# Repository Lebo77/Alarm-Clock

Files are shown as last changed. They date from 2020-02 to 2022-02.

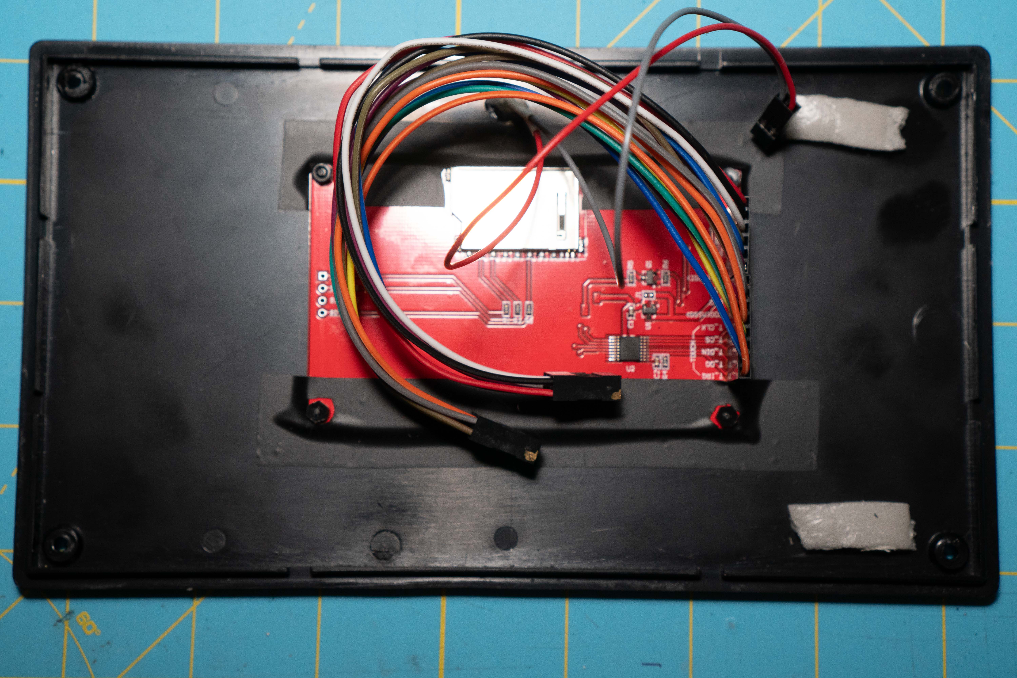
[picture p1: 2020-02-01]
Photos/DSC01666.jpg

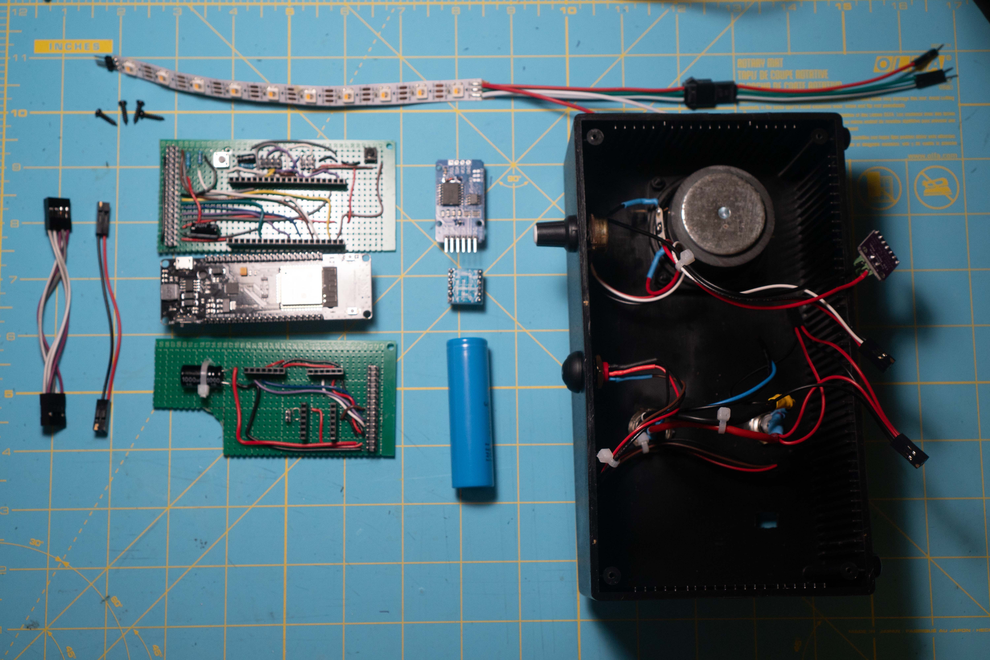
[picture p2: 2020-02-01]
Photos/DSC01659.jpg

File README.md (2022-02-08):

# Alarm-Clock
An ESP32 based alarm clock

This is a bedside alarm clock and light controller I developed. IT relies on a number of external libraries:

OpenWeather by Bodmer
  TFT_eSPI by Bodmer
  JSON_Decoder by Bodmer
  (Thanks Bodmer. This project would not be possible without you)
  ESP8266Audio by Earle F. Pillhower III
  NeoPixelBus by Makuna
  DS3232RTC by Jack Christensen
  Time by Paul Stoffregen
  The ESP32 Board support Package for Arduino by espressif

Thanks and credit to all of them. A few of these files are from Bodmer's libraries. They are included as that is how he intended for them to be employed in the project.

Also included in the KiCad Project directory are the PCB layout files and schematics I used to build my clock.

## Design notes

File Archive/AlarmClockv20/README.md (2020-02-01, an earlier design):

# Alarm-Clock
An ESP32 based alarm clock

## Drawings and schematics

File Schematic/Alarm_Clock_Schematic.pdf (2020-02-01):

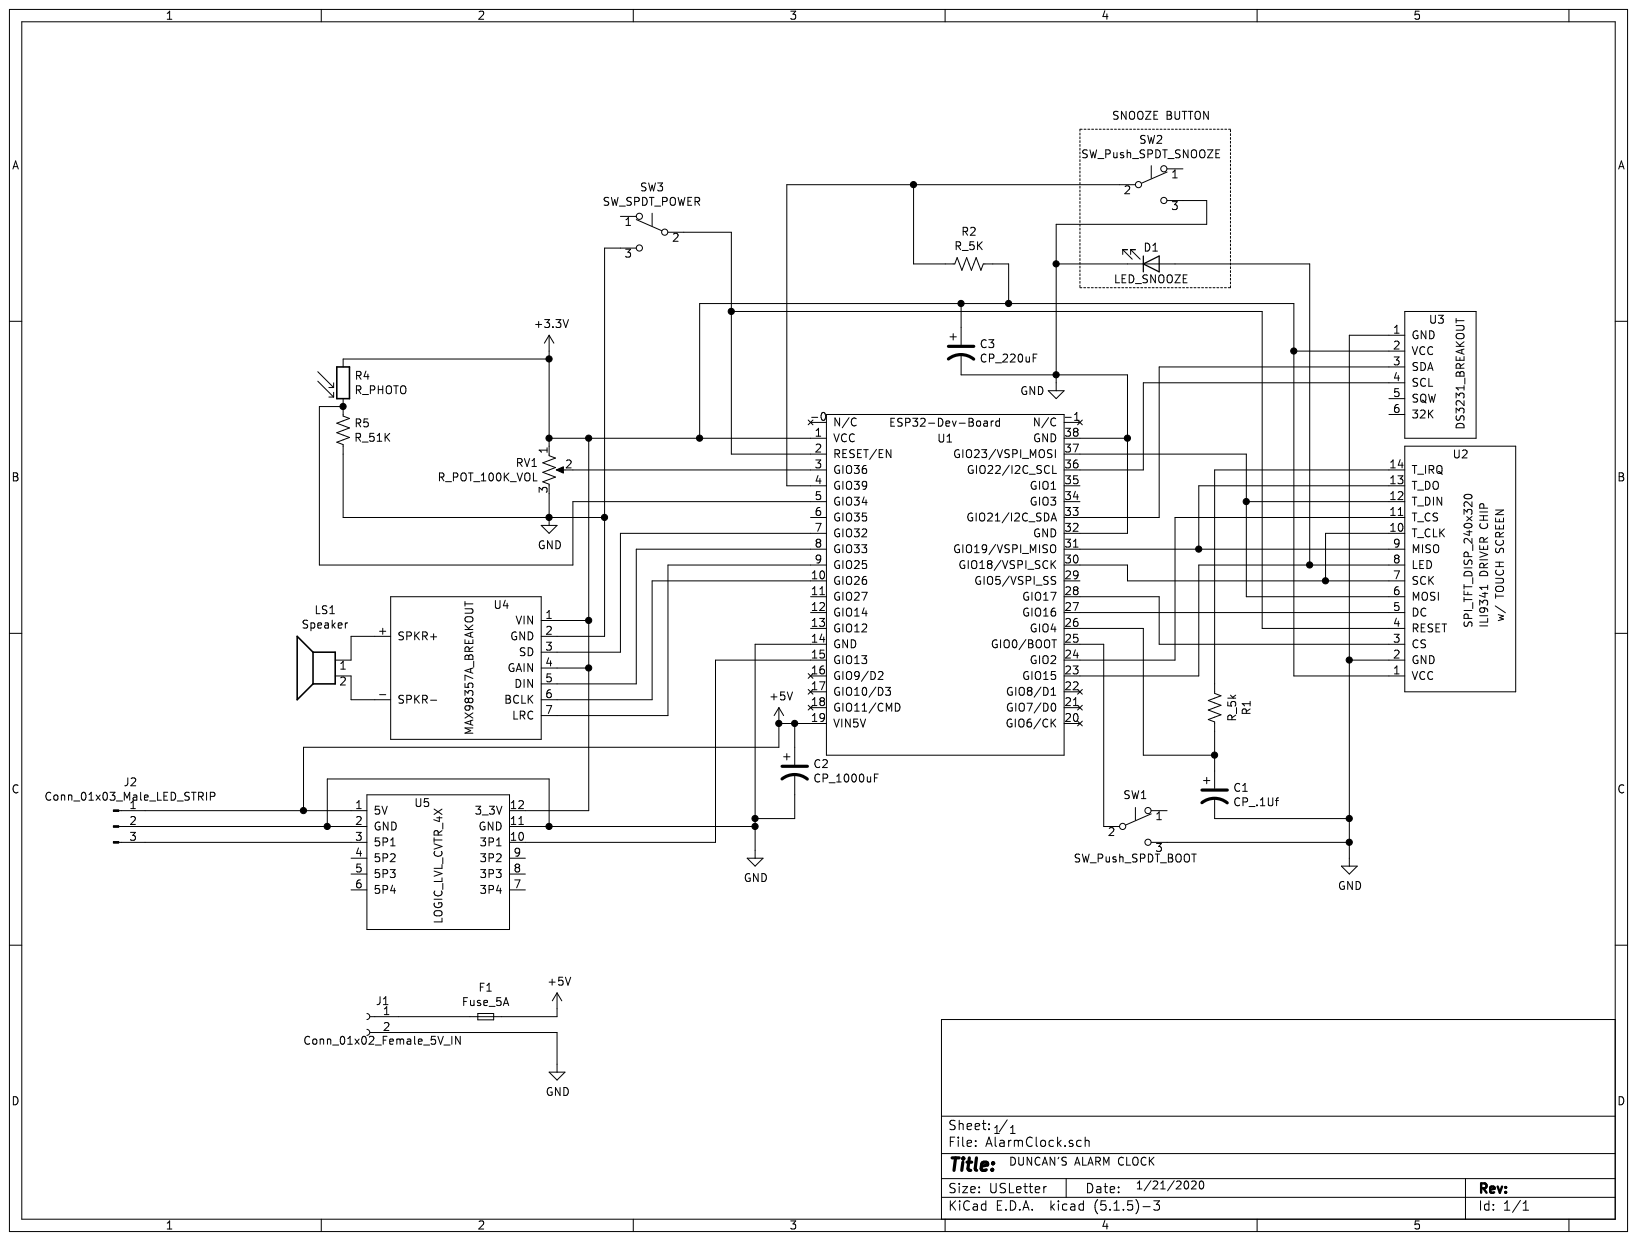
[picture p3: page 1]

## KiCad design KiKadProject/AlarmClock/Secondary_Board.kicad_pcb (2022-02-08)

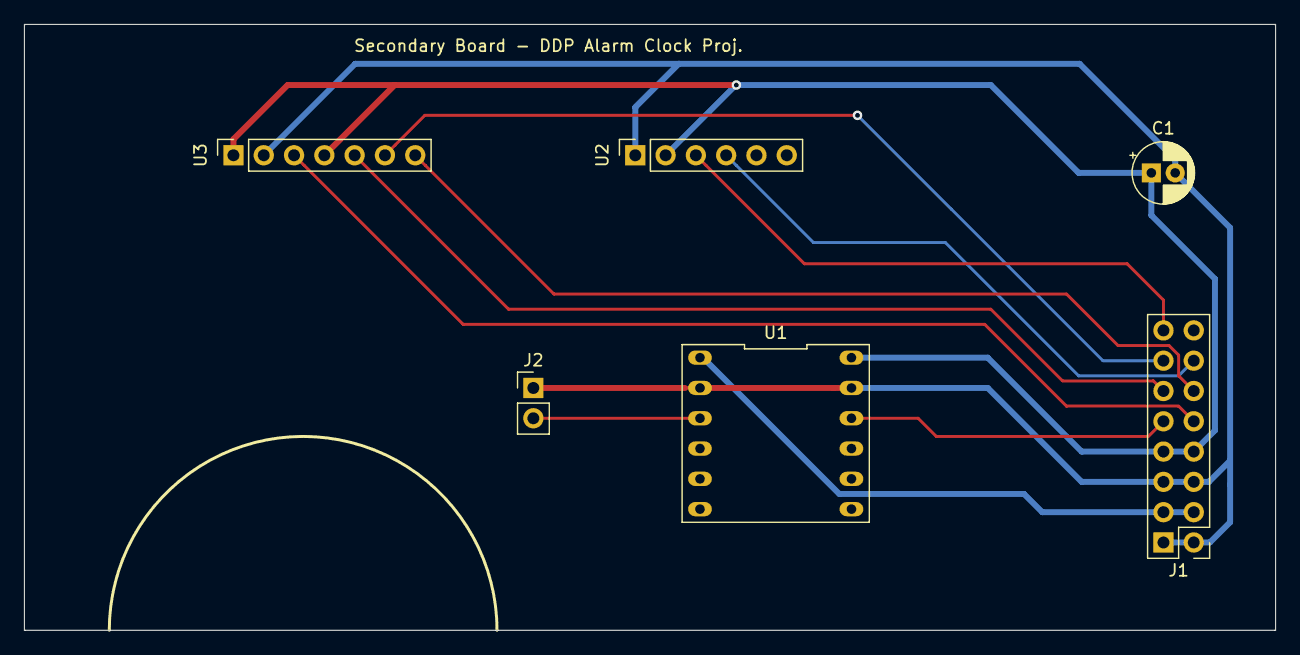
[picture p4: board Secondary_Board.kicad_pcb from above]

Board: 2 copper layers, 104.9 x 50.8 mm, 6 parts (0 on the bottom side), 11 nets.

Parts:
C1: 100uF; CP_Radial_D5.0mm_P2.00mm
J1: Conn_to_Main_Board; PinHeader_2x08_P2.54mm_Vertical_REV
J2: LED_CTRL; PinHeader_1x02_P2.54mm_Vertical
U1: LOGIC_LVL_CVTR_4X; LOGIC_LVL_CVTR_X4
U2: DS3231_BREAKOUT; PinSocket_1x06_P2.54mm_Vertical
U3: MAX98357A_BREAKOUT; PinSocket_1x07_P2.54mm_Vertical

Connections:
+3V3: C1.1, J1.7, J1.8, U1.12, U2.2, U3.1, U3.4
+5V: J1.3, J1.4, U1.1
/AUDIO_BCLK: J1.13, U3.6
/AUDIO_DIN: J1.11, U3.5
/AUDIO_LRC: J1.12, U3.7
/AUDIO_SD: J1.10, U3.3
/I2C_SCL: J1.14, U2.4
/I2C_SDA: J1.15, U2.3
/LED_CTRL: J1.9, U1.10
/LED_CTRL_5V: J2.2, U1.3
GND: C1.2, J1.1, J1.2, J1.5, J1.6, J2.1, U1.2, U1.11, U2.1, U3.2

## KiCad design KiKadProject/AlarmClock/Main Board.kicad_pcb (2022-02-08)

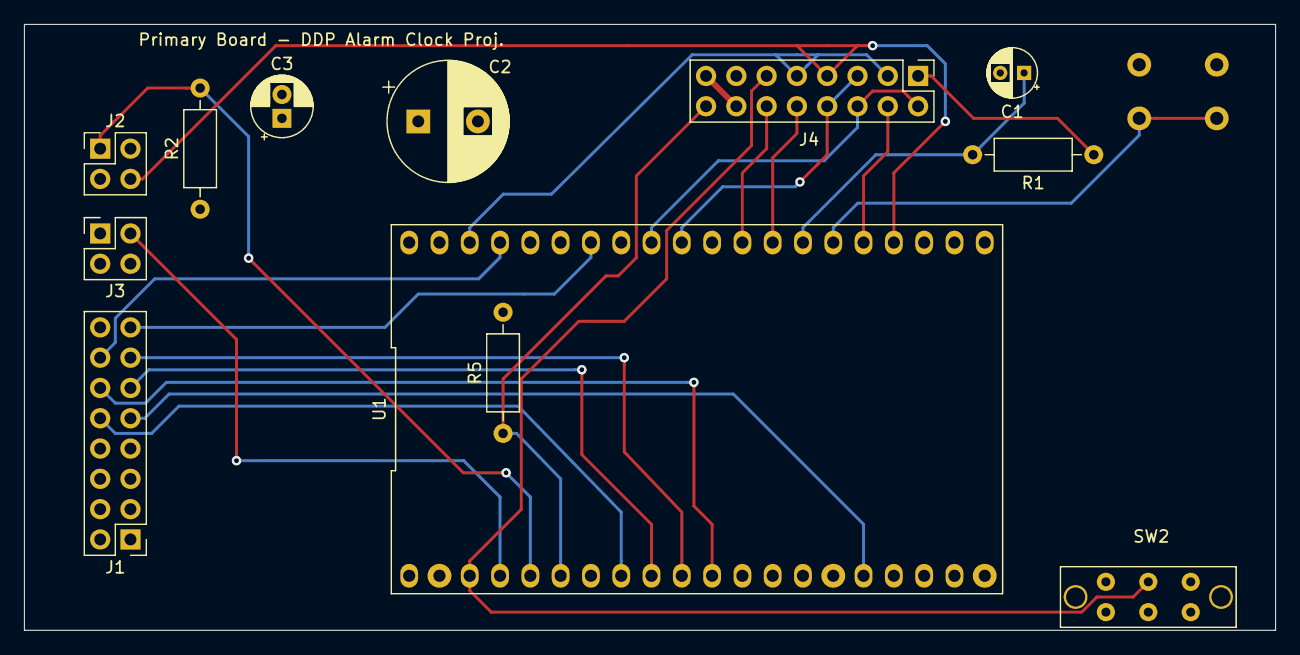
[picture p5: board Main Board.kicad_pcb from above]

Board: 4 copper layers, 104.9 x 50.8 mm, 13 parts (1 on the bottom side), 24 nets.

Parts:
C1: CP_.1Uf; CP_Radial_D4.0mm_P2.00mm
C2: CP_1000uF; CP_Radial_D10.0mm_P5.00mm
C3: CP_220uF; CP_Radial_D5.0mm_P2.00mm
J1: Conn_to_Sec.Board; PinHeader_2x08_P2.54mm_Vertical
J2: SNOOZE_BUTTON; PinHeader_2x02_P2.54mm_Vertical
J3: Volume_Pot; PinHeader_2x02_P2.54mm_Vertical
J4: FRONT_PNL; PinHeader_2x08_P2.54mm_Vertical
R1: R_5k; R_Axial_DIN0207_L6.3mm_D2.5mm_P10.16mm_Horizontal
R2: R_US_5K; R_Axial_DIN0207_L6.3mm_D2.5mm_P10.16mm_Horizontal
R5: R_51K; R_Axial_DIN0207_L6.3mm_D2.5mm_P10.16mm_Horizontal
SW1: SW_Push_BOOT; SW_PUSH_6mm
SW2: SW_SPDT_POWER; SW_SK22H03_2P2T_RA
U1: ESP32-Dev-Board; ESP32_DEV_BOARD

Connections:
+3V3: C3.1, J1.7, J1.8, J3.1, J4.14, J4.15, R2.1, U1.1
+5V: C2.1, J1.3, J1.4, U1.19
/AUDIO_BCLK: J1.13, U1.9
/AUDIO_DIN: J1.11, U1.8
/AUDIO_LRC: J1.12, U1.10
/AUDIO_SD: J1.10, U1.7
/CS: J4.12, U1.28
/DC: J4.10, U1.27
/DIMMING: J2.4, J4.7, U1.23
/I2C_SCL: J1.14, U1.36
/I2C_SDA: J1.15, U1.33
/LED_CTRL: J1.9, U1.15
/LIGHT_SENSE: J4.16, R5.1, U1.5
/MISO: J4.2, J4.6, U1.31
/MOSI: J4.3, J4.9, U1.37
/RESET: J4.11, SW2.2, U1.2
/SCK: J4.5, J4.8, U1.30
/SNOOZE_SWITCH: J2.1, R2.2, U1.4
/T_CS: J4.4, U1.24
/T_IRQ: J4.1, R1.1
/VOLUME_SIG: J3.2, U1.3
GND: C1.2, C2.2, C3.2, J1.1, J1.2, J1.5, J1.6, J2.2, J2.3, J3.3, J4.13, R5.2, SW1.2, SW2.3, U1.14, U1.32, U1.38
unnamed: C1.1, R1.2, U1.26
unnamed: SW1.1, U1.25

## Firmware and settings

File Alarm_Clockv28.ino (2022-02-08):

/*
   Duncan Pickard's over-engineered Alarm Clock

   Master file
*/
#include "globalInclude.h"

// Set up the SPIFFS FLASH filing system
#include <FS.h>
#include "scrolling_sprites.h"

#include <TimeLib.h>
#include <WiFi.h>
#include <WiFiUdp.h>
#include "SPI.h"
#include "SPIFFS.h"
#include "alarm.h"
#include <DS3232RTC.h>      // https://github.com/JChristensen/DS3232RTC
#include <JSON_Decoder.h>
#include <OpenWeather.h>
#include <math.h>
#include "SPIFFS_Support.h"
#include <esp_int_wdt.h>
#include <esp_task_wdt.h>
#include "DisplayMgr.h"
extern "C" {
#include <esp_wifi.h>
}
#include <Preferences.h>
#include "ledCtrl.h"

#define SECONDS_FROM_1970_TO_2000 946684800

// ------------------------------------ Global Variables -----------------------------------------

//  For Demo use

const char ssid[] = "yourSSID";  //  your network SSID (name)
const char pass[] = "yourpassword";       // your network password
const String latitude =  "40.000"; // 90.0000 to -90.0000 negative for Southern hemisphere
const String longitude = "-70.00000"; // 180.000 to -180.000 negative for West
const String api_key = "00000000000000000000000000000000"; // Obtain this from your Dark Sky account
                

// NTP buffer
const int NTP_PACKET_SIZE = 48; // NTP time is in the first 48 bytes of message
byte packetBuffer[NTP_PACKET_SIZE]; //buffer to hold incoming & outgoing packets

// Display management object - holds global interprocess communication variables
displayMgr disp;

// LED light strip management object - holds global interprocess communication variables
ledCtrl ledMaster;

class rollingSprite;
rollingSprite sprite1;
rollingSprite sprite2;
rollingSprite sprite3;

// Non-Volitile storage object
Preferences prefs;

const unsigned int localPort = 8888;  // local port to listen for UDP packets
WiFiUDP Udp;

DS3232RTC RTC(false);  // set up but do not start the RTC
// a mutex to lock the RTC during updates
SemaphoreHandle_t rtcMutex;

// a mutex to lock the ledStrip updates and flash during updates
SemaphoreHandle_t ledMutex;

//A mutex to protect critical code sections
portMUX_TYPE criticalMutex = portMUX_INITIALIZER_UNLOCKED;

// a mutex to protect OpenWeather data
SemaphoreHandle_t owMutex;  // a mutex to lock the owWeather objects

// a mutex to protect OpenWeather data
SemaphoreHandle_t wifiMutex;  // a mutex to lock the wifi interface

OW_Weather ow; // Weather forecast library instance
OW_current *currentA;
OW_hourly *hourlyA;
OW_daily  *dailyA;
OW_current *currentB;
OW_hourly *hourlyB;
OW_daily  *dailyB;
OW_current *current = currentA;
OW_hourly *hourly = hourlyA;
OW_daily  *daily = dailyA;
OW_current *notCurrent = currentB;
OW_hourly *notHourly = hourlyB;
OW_daily *notDaily = dailyB;


uint32_t OwAPICalls = 0;

//  NTP Servers
const String ntpServerName[] = {"us.pool.ntp.org", "time.nist.gov", "time-a.timefreq.bldrdoc.gov", "time-b.timefreq.bldrdoc.gov", "time-c.timefreq.bldrdoc.gov", "time.google.com"} ;

int timeZone = -5; // Leave the NTP time zone as EST for boot up

// set up task handles
TaskHandle_t timeTask;
TaskHandle_t displayTask;
TaskHandle_t spriteTask;
TaskHandle_t modeTask;
TaskHandle_t alarmTask;
TaskHandle_t ledTask;
TaskHandle_t ledDriverTask;

// external alarms
extern alarmData alarm1;
extern alarmData alarm2;
extern alarmData alarm3;

// ------------------------------------ Function prototypes -----------------------------------------
// Functions found in THIS file
void timeMgr( void * parameter);
void setDST(time_t);
bool setRTC(time_t ts);
const char* wl_status_to_string(wl_status_t status);
bool connectToWifi();
void disconnectFromWiFi();
time_t getNtpTime();
time_t getClockTime();
void sendNTPpacket(IPAddress &address);
bool isDST(time_t tn);
bool getCurrentWeather();

// Functions found in DisplayMgmt file
void dispMgr( void * parameter);
void drawWiFiStatus(bool state);
void drawTime(time_t ts, bool repaint);
void drawWeatherIcon(String weatherIcon, int x, int y, bool big);
void drawWeatherDisplay(bool);
void drawCurrentWeatherDisplay(bool);
void drawForecastWeatherDisplay(bool);
void drawAlarmDisplay(bool);
void drawTextString(String msg, uint16_t x, uint16_t y);
void drawTextString(String msg, uint16_t x, uint16_t y, const GFXfont * font, uint16_t padding, uint8_t alignment, uint32_t color, uint32_t bg);
void clearWorkingArea();
void drawAlarmSetDisplay(bool repaint, int alarmNumber);
void drawLightSetDisplay(bool repaint);
String assembleDateStr(time_t ts);
String assembleTimeStr(time_t ts);
String assembleHourlyTimeStr(time_t ts);
String formatWindString(float windSpeed, float windGust , float windBearing);
String formatPrecipString(int type, int prob, float intensity);
String getDayOfWeek(int i);
String getMonthOfYear(int i);
const String getMeteoconIcon(uint16_t id, bool today);

// Functions found in modeMgmt file
void IRAM_ATTR touchISR();
void modeMgr( void * parameter);

// Functions found in scrolling_sprites file
void spriteMgr( void * parameter);

// Functions found in alarmMgmt file
void alarmMgr( void * parameter );

// Functions found in LedMgmt file
void ledMgr( void * parameter);
void ledDriver( void * parameter);

void setup()
{
  Serial.begin(115200);

  Serial.println("*******************************************************************");
  Serial.println("*******************************************************************");
  Serial.println("***                                                             ***");
  Serial.println("***     ***    *****   ***     ***    ***  *****    **   **     ***");
  Serial.println("***     *  *   *       *  *   *   *  *   *   *      **   **     ***");
  Serial.println("***     ***    *****   ***    *   *  *   *   *      **   **     ***");
  Serial.println("***     *  *   *       *  *   *   *  *   *   *                  ***");
  Serial.println("***     *  *   *****   ***     ***    ***    *      **   **     ***");
  Serial.println("***                                                             ***");
  Serial.println("*******************************************************************");
  Serial.println("*******************************************************************");

  if (tftMutex == NULL) {
    tftMutex = xSemaphoreCreateMutex();
  }
  if (tftMutex != NULL) {
    Serial.println("Setup:tftMutex Created.");
  }
  if (owMutex == NULL) {
    owMutex = xSemaphoreCreateMutex();
  }
  if (owMutex != NULL) {
    Serial.println("Setup:owMutex Created.");
  }
  if (rtcMutex == NULL) {
    rtcMutex = xSemaphoreCreateMutex();
  }
  if (rtcMutex != NULL) {
    Serial.println("Setup:rtcMutex Created.");
  }
  if (ledMutex == NULL) {
    ledMutex = xSemaphoreCreateMutex();
  }
  if (ledMutex != NULL) {
    Serial.println("Setup:ledMutex Created.");
  }
  if (wifiMutex == NULL) {
    wifiMutex = xSemaphoreCreateMutex();
  }
  if (wifiMutex != NULL) {
    Serial.println("Setup:wifiMutex Created.");
  }

  esp_task_wdt_init(60, true); // Task WDT set for 60 seconds and reboot if it expires

  prefs.begin("alarms", false);

  if (!SPIFFS.begin()) {
    Serial.println("Setup: ERROR! SPIFFS initialisation failed!");
  }
  else {
    Serial.println("Setup: SPIFFS initialised.");
  }

  xSemaphoreGive(rtcMutex); // give the RTC mutex something to access

  // spawn the display manager process
  xTaskCreatePinnedToCore(
    dispMgr, /* Function to implement the task */
    "dispMgr", /* Name of the task */
    10000,  /* Stack size in words */
    NULL,  /* Task input parameter */
    1,  /* Priority of the task */
    &displayTask,  /* Task handle. */
    1 /* Core */
  );

  int i2CRtn = I2C_ClearBus(true); // Reset the RTC bus w/ a 2.5 sec delay for RTC start-up
  if (i2CRtn != 0) {
    Serial.println(F("Setup: I2C bus error. Could not clear"));
    if (i2CRtn == 1) {
      Serial.println(F("Setup: SCL clock line held low"));
    } else if (i2CRtn == 2) {
      Serial.println(F("Setup: SCL clock line held low by slave clock stretch"));
    } else if (i2CRtn == 3) {
      Serial.println(F("Setup: SDA data line held low"));
    }
  } else { // bus clear
    Serial.println(F("Setup: I2C setup finished"));
  }

  // spawn the time manager process
  xTaskCreate(
    timeMgr, /* Function to implement the task */
    "timeMgr", /* Name of the task */
    10000,  /* Stack size in words */
    NULL,  /* Task input parameter */
    1,  /* Priority of the task */
    &timeTask  /* Task handle. */
  );

  // spawn the sprite manager process
  xTaskCreate(
    spriteMgr, // Function to implement the task
    "spriteMgr", // Name of the task
    2000,  // Stack size in words
    NULL,  // Task input parameter
    3,  // Priority of the task
    &spriteTask);  // Task handle.

  // spawn the mode manager process
  xTaskCreatePinnedToCore(
    modeMgr, // Function to implement the task
    "modeMgr", // Name of the task
    4000,  // Stack size in words
    NULL,  // Task input parameter
    2,  // Priority of the task
    &modeTask, // Task handle.
    1);  // Core

  // spawn the alarm manager process
  xTaskCreatePinnedToCore(
    alarmMgr, // Function to implement the task
    "alarmMgr", // Name of the task
    4000,  // Stack size in words
    NULL,  // Task input parameter
    5,  // Priority of the task
    &alarmTask,  // Task handle.
    1 // Core
  );

  // spawn the led manager process
  xTaskCreatePinnedToCore(
    ledMgr, // Function to implement the task
    "ledMgr", // Name of the task
    2000,  // Stack size in words
    NULL,  // Task input parameter
    1,  // Priority of the task
    &ledTask,  // Task handle.
    1 // Core
  );

  // spawn the led driver process
  xTaskCreatePinnedToCore(
    ledDriver, // Function to implement the task
    "ledDriver", // Name of the task
    2000,  // Stack size in words
    NULL,  // Task input parameter
    4,  // Priority of the task
    &ledDriverTask,  // Task handle.
    0 // Core
  );
}

void loop()
{
  // empty, all work done in tasks
  vTaskDelay(portMAX_DELAY);
  vTaskDelete( NULL );
}

//================================================================
//================ Time Manager ==================================
//================================================================
void timeMgr( void * parameter) {

  extern SemaphoreHandle_t alarmSemaphore;

  if (xSemaphoreTake(rtcMutex, (TickType_t) 250) == pdTRUE ) {
    RTC.begin(); // start the clock
    xSemaphoreGive(rtcMutex);
  }
  else {
    Serial.println("timeMgr: Unable to get RTC Mutex");
  }

  if ( esp_task_wdt_add(NULL) != ESP_OK) { // add task to WDT
    Serial.println("Unable to add timeMgr to taskWDT!");
  }

  static uint8_t hourPrevious;
  static uint8_t minutePrevious;
  static uint8_t dayPrevious;

  time_t tn;

  if (xSemaphoreTake(rtcMutex, (TickType_t) 250) == pdTRUE ) {
    tn = RTC.get();
    if (RTC.oscStopped(true) || tn <= 0) { // the clock has stopped and needs to be reset
      Serial.println("timeMgr: The RTC stopped. Resetting from the Internet");
      tn = getNtpTime();
      if (!RTC.set(tn)) {
        Serial.println("timeMgr: Write to RTC FAILED!!!");
      }
      setTime(tn + (timeZone * SECS_PER_HOUR) + 1 );
    }
    else {
      setTime(tn + (timeZone * SECS_PER_HOUR) + 1 );
    }
    xSemaphoreGive(rtcMutex);
  }
  else {
    Serial.println("timeMgr: Unable to get RTC Mutex");
  }

  // setSyncInterval(75);
  setDST(now());
  // setSyncProvider(getClockTime);

  if (esp_task_wdt_reset() != ESP_OK) {
    Serial.println("timeMgr: Unable to reset timeMgr taskWDT!");
  }

  if (getCurrentWeather()) {
    Serial.println("timeMgr: Startup Weather Check Successful");
    disp.setDrawLowerScreen(true);
  }
  else {
    Serial.println("timeMgr: Startup Weather Check Successful");
  }


  TickType_t xLastWakeTime;
  const TickType_t xFrequency = 500 / portTICK_PERIOD_MS; // Run the loop twice a second
  xLastWakeTime = xTaskGetTickCount();

  for (;;) { // Begin main loop

    time_t ts = now();
    uint8_t minuteNow = minute(ts);

    if (minuteNow != minutePrevious) {
      minutePrevious = minuteNow;

      // Test the alarms
      if (alarm1.alarmTest(ts)) {
        Serial.println("timeMgr: ALARM1!!!");
        disp.setAlarmRinging(1);
        xSemaphoreGive(alarmSemaphore);
      }
      else if (alarm2.alarmTest(ts)) {
        Serial.println("timeMgr: ALARM2!!!");
        disp.setAlarmRinging(2);
        xSemaphoreGive(alarmSemaphore);
      }
      else if (alarm3.alarmTest(ts)) {
        Serial.println("timeMgr: ALARM3!!!");
        disp.setAlarmRinging(3);
        xSemaphoreGive(alarmSemaphore);
      }

      if (minuteNow % 5 == 0) {
        // Every 5 minutes, print heap status
        Serial.println("timeMgr: Current free data memory: " + String(xPortGetFreeHeapSize()));
        Serial.println("timeMgr: Minimum free data memory: " + String(xPortGetMinimumEverFreeHeapSize()));

        setTime(getClockTime()); // set the CPU time from the RTC

        if (disp.getAlarmRinging() != 0)
        { // don't try and get the weather if there is an alarm going off. Try in 2.5 minutes
          Serial.println("timeMgr: Alarm is ringing. skip getting the weather.");
        }
        else {
          Serial.println("timeMgr: Getting the weather from OpenWeather.");
          if (getCurrentWeather()) {
          }
          else {
            Serial.println("timeMgr: Failed to retrieve weather!");
          }
        }
        disp.setDrawLowerScreen(true); // set the lower screen to be redrawn every 5 minutes
      }

      if (hour(ts) != hourPrevious) { // this is to check to see if we go into or out of DST
        Serial.println("timeMgr: BONG! new hour. Running hourly tasks.");
        hourPrevious = hour(ts);
        // check NTP once an hour
        if (disp.getAlarmRinging() == 0) { // don't try and get the time if there is an alarm going off! Try in 2 minutes
          if (setRTC(getNtpTime())) {
            Serial.println("timeMgr: RTC set from from NTP server");
          }
          else {
            Serial.println("timeMgr: Unable to set RTC from NTP server.");
          }
        }
        setDST(ts); // check to see if DST status changed
      }

      if (day(ts) != dayPrevious) { // Run Daily Tasks
        Serial.println("timeMgr: BONG! new day. Running daily tasks.");
        dayPrevious = day(ts);
        OwAPICalls  = 0;
        disp.setFullReDraw(true); // force a full screen re-paint
      }
    }

    if (xPortGetMinimumEverFreeHeapSize() < 2048) { // Reset if we ever get to less than 2K of free memory
      Serial.println("\n\ntimeMgr: ========================================");
      Serial.println("timeMgr: Minimum free memory too low. Restarting.");
      Serial.println("timeMgr: ========================================\n\n");
      ESP.restart();
    }

    if (esp_task_wdt_reset() != ESP_OK) {
      Serial.println("timeMgr: Unable to reset timeMgr taskWDT!");
    }

    vTaskDelayUntil( &xLastWakeTime, xFrequency );
  }
}

//================================================================
//================ Get NTP Time ==================================
//================================================================
time_t getNtpTime() {

  char serverName [50];
  IPAddress ntpServerIP; // NTP server's ip address

  Serial.println("Wifi status is: " + String(wl_status_to_string(WiFi.status())));

  if (xSemaphoreTake(wifiMutex, (TickType_t) 200) == pdTRUE ) {

    if (WiFi.status() != WL_CONNECTED) {
      if (connectToWifi() == false) {
        Serial.println("getNtpTime: Unable to get NTP Time. Disconnecting.");
        disp.setCurrWiFiStatus(false);
        disconnectFromWiFi();
        xSemaphoreGive(wifiMutex);
        return 0;
      }
    }

    while (Udp.parsePacket() > 0) ; // discard any previously received packets

    for (int i = 0; i < (sizeof(ntpServerName) / sizeof(ntpServerName[0])); i++)
    {
      Serial.println("getNtpTime: Transmit NTP Request");
      ntpServerName[i].toCharArray(serverName, 50);
      WiFi.hostByName(serverName, ntpServerIP);
      Serial.print(serverName);
      Serial.print(": ");
      Serial.println(ntpServerIP);
      sendNTPpacket(ntpServerIP);
      uint32_t beginWait = millis();
      while (millis() - beginWait < 2500) {
        int size = Udp.parsePacket();
        if (size >= NTP_PACKET_SIZE) {
          Serial.println("getNtpTime: Receive NTP Response");
          Udp.read(packetBuffer, NTP_PACKET_SIZE);  // read packet into the buffer
          unsigned long secsSince1900;
          // convert four bytes starting at location 40 to a long integer
          secsSince1900 =  (unsigned long)packetBuffer[40] << 24;
          secsSince1900 |= (unsigned long)packetBuffer[41] << 16;
          secsSince1900 |= (unsigned long)packetBuffer[42] << 8;
          secsSince1900 |= (unsigned long)packetBuffer[43];
          disp.setCurrWiFiStatus(true);
          disconnectFromWiFi();
          xSemaphoreGive(wifiMutex);
          drawWiFiStatus(true);
          //Serial.println("getNtpTime: recieved time: " + String(secsSince1900 - 2208988800UL));
          Serial.print("getNtpTime: Recieved time: ");
          Serial.println(secsSince1900 - 2208988800UL);
          return secsSince1900 - 2208988800UL;
        }
      }
      Serial.println("getNtpTime: No NTP Response from " + String(serverName));
    }
    disp.setCurrWiFiStatus(false);
    Serial.println ("getNtpTime: Failed to get NTP time. Disconnecting");
    disconnectFromWiFi();
    xSemaphoreGive(wifiMutex);
    drawWiFiStatus(false);
    return 0; // return 0 if unable to get the time
  }
  else {
    Serial.println("getNtpTime: Unable to get wifi Mutex");
    return 0; // return 0 if unable to get the time
  }
}

//================================================================
//================ Send NTP Packet ===============================
//================================================================
// send an NTP request to the time server at the given address
void sendNTPpacket(IPAddress & address) {
  // set all bytes in the buffer to 0
  memset(packetBuffer, 0, NTP_PACKET_SIZE);
  // Initialize values needed to form NTP request
  // (see URL above for details on the packets)
  packetBuffer[0] = 0b11100011;   // LI, Version, Mode
  packetBuffer[1] = 0;     // Stratum, or type of clock
  packetBuffer[2] = 6;     // Polling Interval
  packetBuffer[3] = 0xEC;  // Peer Clock Precision
  // 8 bytes of zero for Root Delay & Root Dispersion
  packetBuffer[12] = 49;
  packetBuffer[13] = 0x4E;
  packetBuffer[14] = 49;
  packetBuffer[15] = 52;
  // all NTP fields have been given values, now
  // you can send a packet requesting a timestamp:
  Udp.beginPacket(address, 123); //NTP requests are to port 123
  Udp.write(packetBuffer, NTP_PACKET_SIZE);
  Udp.endPacket();
}

//================================================================
//================ Connect to WiFi ===============================
//================================================================
// Connect to the WiFi network
bool connectToWifi() {
  int retryCount = 0;
  int tryTimeout;
  while (WiFi.status() != WL_CONNECTED && retryCount < 3) {
    tryTimeout = 0;
    retryCount++;
    Serial.print("connectToWifi: WiFi disconnected. Reason code: ");
    Serial.println(wl_status_to_string(WiFi.status()));
    Serial.print("connectToWifi: Try #: ");
    Serial.println(retryCount);
    Serial.println("connectToWifi: WiFi connect");
    Serial.print("connectToWifi:     Connecting to ");
    Serial.println(ssid);
    WiFi.begin(ssid, pass);

    while (WiFi.status() != WL_CONNECTED && tryTimeout < 60) {
      tryTimeout++;
      vTaskDelay(250 / portTICK_PERIOD_MS);
      Serial.print(".");
    }
    Serial.println(" ");

    if (WiFi.status() != WL_CONNECTED) { // Failed to connect
      disconnectFromWiFi();
      vTaskDelay(1000 / portTICK_PERIOD_MS);
    }
  }

  if (WiFi.status() != WL_CONNECTED) {
    Serial.println("connectToWifi: Connection Failed");
    return false;
  }
  else {
    Serial.println();
    Serial.print("connectToWifi: IP number assigned by DHCP is ");
    Serial.println(WiFi.localIP());
    Serial.print("connectToWifi: DNS IP: ");
    Serial.println(WiFi.dnsIP());
    Serial.println("connectToWifi: Starting UDP");
    Udp.begin(localPort);
    Serial.print("connectToWifi: Local port: ");
    Serial.println(localPort);
    return true;
  }
}

//================================================================
//============= Disconnect From WiFi =============================
//================================================================
// Disconnect from the network
void disconnectFromWiFi() {
  Serial.println("disconnectFromWiFi: WiFi closing down.");
  ESP_ERROR_CHECK( esp_wifi_disconnect());
  vTaskDelay(10 / portTICK_PERIOD_MS);
}
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

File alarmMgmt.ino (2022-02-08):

// This file manages the Alarms for the clock.

#include "globalInclude.h"

#include "AudioFileSourceSPIFFS.h"
#include "AudioGeneratorWAV.h"
#include "AudioOutputI2S.h"

// #define ALARM_OFF_BUTTON 35
#define ALARM_OFF_BUTTON 39
#define VOLUME_POT 36

#define LRCLK_PIN 26
#define BCLK_PIN 25
#define DOUT_PIN 33
#define AUDIO_SHUTDOWN_PIN 32

#define MAX_ALARM_TIME 3600

//Time in ms to wat before shutting off the alarm vs. snoozing
#define ALARM_BUTTON_TIME 1750

// =============================================
// ================ Globals ====================
// =============================================
AudioGeneratorWAV *wav;
AudioFileSourceSPIFFS *file;
AudioOutputI2S *out;

// create the three alarms
class alarmData;
alarmData alarm1;
alarmData alarm2;
alarmData alarm3;

SemaphoreHandle_t alarmSemaphore = NULL; // handle for the alarm semaphore

//===================================================================
//====================== Start WAV ==================================
//===================================================================
void startWAV(String filename) {
  delete file;
  char filenameChar[31];
  filename.toCharArray(filenameChar, 31);
  file = new AudioFileSourceSPIFFS(filenameChar);
  digitalWrite(AUDIO_SHUTDOWN_PIN, HIGH);
  wav->begin(file, out);
}

//===================================================================
//====================== Ring Alarm =================================
//===================================================================
void ringAlarm( uint8_t alarmNum ) {

  unsigned long buttonDownTime;

  time_t alarmStartTime = now(); // Don't play the alarm for more than an hour

  alarmData *workAlarm;
  if (alarmNum == 1) {
    workAlarm = &alarm1;
  }
  else if (alarmNum == 2) {
    workAlarm = &alarm2;
  }
  else if (alarmNum == 3) {
    workAlarm = &alarm3;
  }

  TickType_t xLastWakeTime;
  const TickType_t xFrequency = 10 / portTICK_PERIOD_MS;
  xLastWakeTime = xTaskGetTickCount();
  for (;;) {
    time_t ts = now();


    // set the volume
    float snoozeAdjust = (0.15 * (float)(workAlarm->isSnoozed()));
    if (snoozeAdjust > 0.8) snoozeAdjust = 0.8;
    float volumeIn =  (((float)analogRead(VOLUME_POT) / 1900.0) ) + 0.3 + snoozeAdjust; // allow up to a 2.46 amplification, with a minimum of 0.3 + snoozeAdjust
    out->SetGain(volumeIn);

    if (xSemaphoreTake(ledMutex, (TickType_t) 5) == pdTRUE ) {
      if (ts - alarmStartTime > MAX_ALARM_TIME) { // Turn off the alarm after the maximum allowable time
        Serial.println("ringAlarm: " + workAlarm->getAlarmID() + " has timed out. Stopping alarm audio.");
        disp.setAlarmRinging(0);
        wav->stop();
        digitalWrite(AUDIO_SHUTDOWN_PIN, LOW);
        drawAlarmIndicator(false);
        return;
      }

      if (disp.getAlarmRinging()) {
        if (digitalRead(ALARM_OFF_BUTTON) == LOW) { // Stop the alarm
          Serial.println("ringAlarm: Saw Alarm Off button. Stopping alarm audio.");
          disp.setAlarmRinging(0);
          wav->stop();
          digitalWrite(AUDIO_SHUTDOWN_PIN, LOW);
          ledMaster.stopFlashing(); // stop the flashing if any
          buttonDownTime = millis();
          disp.resetlastTouch(); // backlight dimming
        }
        else if (!workAlarm->isActive()) { // someone turned off the alarm directly
          Serial.println("ringAlarm: Alarm is no longer active. Stopping audio.");
          disp.setAlarmRinging(0);
          wav->stop();
          digitalWrite(AUDIO_SHUTDOWN_PIN, LOW);
          ledMaster.stopFlashing(); // stop the flashing if any
          disp.resetlastTouch(); // backlight dimming
          xSemaphoreGive(ledMutex);
          return;
        }
        else if (wav->isRunning()) { // fill the buffer
          if (!wav->loop()) wav->stop();
        }
        else { // restart the audio
          startWAV("/alarm" + String(disp.getAlarmRinging()) + ".wav");
          //If snoozing has been going for a while, flash the lights.
          if (workAlarm->isSnoozed() >= 3 ) ledMaster.startFlashing();
        }
      }
      else { // The button has been pressed, but are we snoozed or are we turning off the alarm?
        unsigned long buttonTotalTime = millis() - buttonDownTime;
        if (digitalRead(ALARM_OFF_BUTTON) == HIGH) { // the button has been released
          if (buttonTotalTime < ALARM_BUTTON_TIME) { // less than 1.75 seconds and we are snoozed
            Serial.println ("ringAlarm: Time elapsed: " + String(buttonTotalTime) + "ms");
            Serial.println ("ringAlarm: Button released snoozing " + workAlarm->getAlarmID());
            workAlarm->snooze();
            xSemaphoreGive(ledMutex);
            ledMaster.stopFlashing(); // if flashing, stop
            return;
          }
        }
        if (millis() - buttonDownTime > ALARM_BUTTON_TIME) { // over the time seconds and we discontinue the alarm
          Serial.println ("ringAlarm: Time elapsed: " + String(buttonTotalTime) + "ms");
          Serial.println ("ringAlarm: Button released reseting " + workAlarm->getAlarmID());
          workAlarm->resetSnooze();
          drawAlarmIndicator(false);
          if (workAlarm->isSunriseActive()) { // Sunrise alarm is active
            ledMaster.roomLightOn(); // turn room light on
            disp.setDrawTimeSection(true);
          }
          xSemaphoreGive(ledMutex);
          ledMaster.stopFlashing(); // if flashing, stop
          return;
        }
      }

      if (esp_task_wdt_reset() != ESP_OK) {
        Serial.println("ringAlarm: Unable to reset alarmMgr taskWDT!");
      }
      xSemaphoreGive(ledMutex);
      vTaskDelayUntil( &xLastWakeTime, xFrequency );
    }
  }
}
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

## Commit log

2020-02-01 Adding schematic
2020-02-01 Updated. Added photos and schematic
2022-02-08 Version 0.5
    Update to latest Revision. Significant bugfixes and improvements.
    [Alarm_Clockv28.ino, DisplayMgmt.ino, LedMgmt.ino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]
2022-02-08 Adding Board layout files and schematics.
    [AlarmClock.sch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]
